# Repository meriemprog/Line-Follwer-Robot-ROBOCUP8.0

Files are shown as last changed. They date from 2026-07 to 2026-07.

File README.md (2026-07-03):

map
Readme · MDPID Line-Follower Robot (ESP32)

An autonomous line-following robot built for competition, running on an ESP32 microcontroller. The robot uses a 6-sensor IR array with a PID control loop to track a line, handles inverted-color (color-swap) track sections, and includes timed maneuver phases tuned for a specific competition course.

Features

6-channel IR sensor array with automatic calibration (white surface / black line) at startup
PID line-tracking control (tunable Kp, Ki, Kd) with anti-windup protection on the integral term
Weighted error calculation — sensor weights can be reconfigured per track segment for sharper or gentler corrections
Timed maneuver sequencing — the main loop uses millis()-based time windows to switch between different speed/PID/weight profiles for different sections of the course (start, straights, curves, etc.)
Inverted-line detection & handling — a dedicated routine (readSensorsinv) detects and follows color-swapped track sections where black/white are reversed
Automatic stop condition — the robot halts when it detects a full stop-line (all 6 sensors active) after completing the course
Push-button start — robot waits for a button press before beginning its run, allowing manual placement on the track
Onboard LED status indicator — used during calibration and inverted-line phases

Hardware

ComponentDescriptionMicrocontrollerESP32Line sensors6x IR/reflectance sensors (analog)Motor driver2x DC motors, H-bridge style (forward/reverse PWM pins per motor)Push buttonUsed to trigger the start of the runOnboard LEDStatus indicator during calibration

Pinout

SignalPinLeft Motor ForwardGPIO 4Left Motor BackwardGPIO 16Right Motor ForwardGPIO 17Right Motor BackwardGPIO 18Status LEDGPIO 2Start ButtonGPIO 34IR Sensors (0–5)GPIO 32, 33, 25, 26, 27, 13

How It Works

Calibration — On boot, the robot is placed on a white surface, then on the black line, so each sensor's min/max reflectance values are recorded (~13s process). Calibration values are printed over Serial for debugging.
Start trigger — The robot waits for a button press before beginning its run.
Line tracking loop — Each cycle:

Reads and binarizes all 6 sensors against the calibrated threshold
Computes a weighted position error from active sensors
Runs the PID controller on the error to produce a correction output
Converts the PID output into differential left/right motor speeds

Course-specific phases — The main loop() uses elapsed time (millis() - t0) to switch between different weight sets, base speeds, and Kp values for different segments of the known competition track.
Inverted-color handling — If the sensor pattern matches a color-inverted section (outer sensors triggered, center sensors not), the robot switches to an inverted read/response routine until it exits that section.
Finish detection — Once the robot detects a full black stop-line (all 6 sensors active) after completing the inverted section, it stops both motors and halts execution.

Configuration

Key tunable parameters near the top of the file:

cppfloat Kp = 43;
float Ki = 0.0005;
float Kd = 8;

int baseSpeed = 150;   // base cruising speed (0–255)
int maxSpeed  = 255;
int minSpeed  = 30;

These — along with the per-segment weights arrays inside loop() — are the main values to retune when adapting the robot to a new track layout.

Usage

Flash competition_code.ino to the ESP32 via the Arduino IDE (select the correct ESP32 board profile).
Open the Serial Monitor at 115200 baud to view calibration output and debug logs.
Power on the robot with it placed on a white area of the track; wait for the LED to turn on/off (white calibration phase).
Move the robot onto the black line when prompted; wait for calibration to complete.
Press the start button to begin the run.
The robot will follow the line autonomously and stop automatically at the finish/stop-line.

Notes

Some code comments and variable names are in French/Darija (e.g. t_lekhra, khrouj, test_tri9_twil), reflecting the original development context — functionally these track timing and state flags for the inverted-line exit sequence.
The timed phases in loop() are tuned for a specific competition track and will need to be re-calibrated (both timings and sensor weights) if reused on a different course. [Uploading CDC-SUIVEUR.pdf…]()

https://github.com/user-attachments/assets/bd51bef6-24f9-4c43-a9d5-c52722ca410f

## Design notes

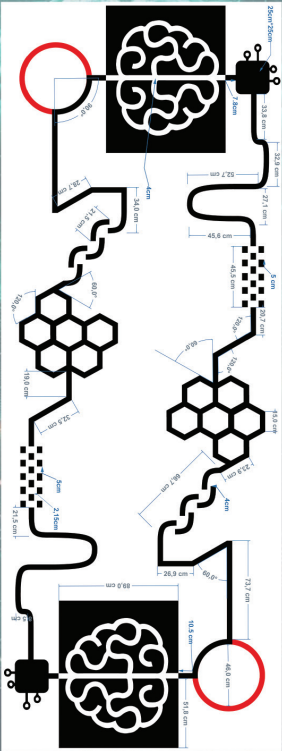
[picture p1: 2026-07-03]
map.png

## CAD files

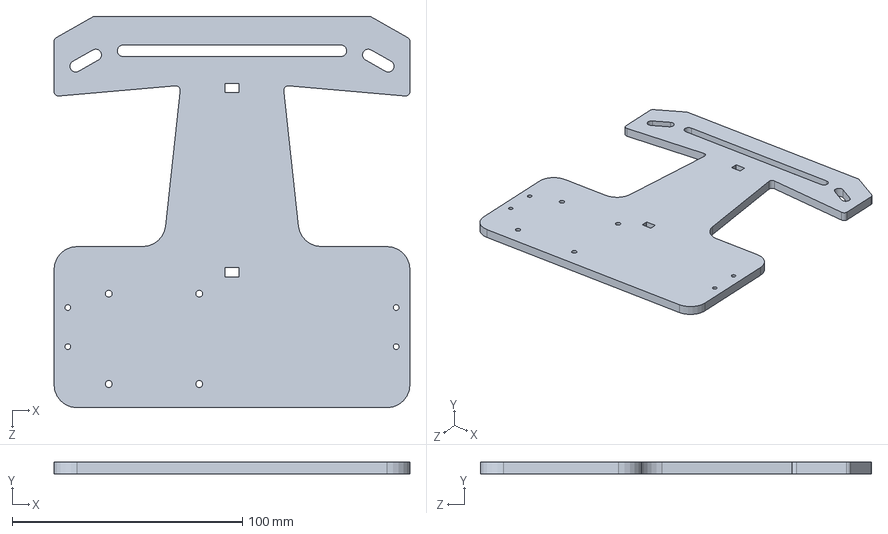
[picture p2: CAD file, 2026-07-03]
Base Conception.sldprt
154.6 x 5.00 x 170.0 mm

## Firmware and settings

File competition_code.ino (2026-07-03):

'"#include<vector>
  //temps de calibrage =13s
  using namespace std;
  const int ML_F = 4;  // PWM pin for Motor A direction 1
  const int ML_B = 16;  // PWM pin for Motor A direction 2  
  const int MR_F = 17;  // PWM pin for Motor B direction 1
  const int MR_B = 18; // PWM pin for Motor B direction 2
  #define LED 2 // internal led 
  const int btnpin=34;
  const int sensorPins[6] = {32,33,25,26,27,13}; 
  float Kp = 43; 
  float Ki = 0.0005; 
  float Kd = 8 ;   
  int error = 0;                  
  int previousError = 0;  
  float integralTerm=0; 
  int derivative = 0; 
  int pidOutput =0;
  bool cerclemode=false;
  bool flechemode=false;
  // Motor Speed Parameters
  int baseSpeed =150;     // Base speed when robot is on line (0-255)
  int maxSpeed = 255;      // Maximum allowed speed
  int minSpeed = 30;       // Minimum speed to overcome friction
  // Sensor Values and Calibration
  int sensorValues[6];     // Raw sensor readings
  int sensorCalibrated[6]; // Calibrated sensor values
  int valblanc[6];        // Minimum values during calibration
  int valnoir[6];        // Maximum values during calibration
  int sensorMin[6]={4095,4095,4095,4095,4095,4095};
  int sensorMax[6]={0,0,0,0,0,0};
  unsigned int t_lekhra ; // instance de khrouj ml couleur inverséée
  bool test_tri9_twil = false;
  unsigned int t0;
  int k=0;
  int k1=0;
  int k2=0;
  int activeCountBefore=0;
  bool test1=false;
  int khrouj =0;



  //Line Position (0 = centered, negative = left, positive = right)
  int linePosition = 0;
  vector<double> weights = {5, 3, 1, -1, -3, -5};
  vector<int>weightscercle={9,7,1,-1,-3,-5};
  void calibrateSensors() {
    int valBlanc[6] = {0, 0, 0, 0, 0, 0};
    int valNoir[6]  = {0, 0, 0, 0, 0, 0};



    Serial.println("=== Calibration Start ===");
    Serial.println("Step 1: Place robot on WHITE area");

    delay(2000); // Time to place it manually
    digitalWrite(LED,HIGH);

    // Measure white surface
    for (int j = 0; j < 50; j++) {
      for (int i = 0; i < 6; i++) {
        valBlanc[i] += abs(analogRead(sensorPins[i]));
      }
      delay(50);
    }
    digitalWrite(LED,LOW);

    delay(2000);
    Serial.println("Step 2: Place robot on BLACK line");
    delay(3000);

    digitalWrite(LED,HIGH);

    // Measure black surface
    for (int j = 0; j < 50; j++) {
      for (int i = 0; i < 6; i++) {
        valNoir[i] +=abs(analogRead(sensorPins[i]));
      }
      delay(50);
    }
    digitalWrite(LED,LOW);

    // Compute average values and save them as min/max calibration
    for (int i = 0; i < 6; i++) {
      sensorMin[i] = abs(valBlanc[i]) / 50;  // White = min reflectivity
      sensorMax[i] = abs(valNoir[i]) / 50;   // Black = max reflectivity
      if (sensorMax[i] < sensorMin[i]) {  // swap if reversed
        int temp = sensorMax[i];
        sensorMax[i] = sensorMin[i];
        sensorMin[i] = temp;
      }
    }


    Serial.println("Calibration complete!");
    for (int i = 0; i < 6; i++) {
      Serial.print("Sensor ");
      Serial.print(i);
      Serial.print(" -> Min: ");
      Serial.print(sensorMin[i]);
      Serial.print("  Max: ");
      Serial.println(sensorMax[i]);
    }
    Serial.println("=========================");
  }
  // MIN of an array 
  int Min(int* T) {
    int min=T[0];
    for(int i=0;i<6;i++){
      if(T[i]<=min){
        min=T[i];
      }
    }
    return min;
  }
  int Max(int* T) {
    int max=T[0];
    for(int i=0;i<6;i++){
      if(T[i]>=max){
        max=T[i];
      }
    }
    return max;
  }
  int stop = 0;

  void readSensors() {
    /*
    * Reads all 6 sensors and converts to binary values
    * Applies calibration to get consistent readings
    */
    for (int i = 0; i < 6; i++) {
      int rawValue = analogRead(sensorPins[i]);
      
      // Apply calibration: map to 0-1000 range
      int calibratedValue = map(rawValue, sensorMin[i], sensorMax[i], 0, 4095);
      
      // Constrain values and convert to binary (0 or 1)
      //calibratedValue = constrain(calibratedValue, 0, 1000);
      sensorCalibrated[i] = (calibratedValue > (Max(sensorMin)+Min(sensorMax))/2) ? 1 : 0; 
    }
  }
  void calculateError() {
    /*
    * Calculates position error based on sensor readings
    * Uses weighted position method for better accuracy
    * Sensor positions: [0, 1, 2, 3, 4, 5] from left to right
    * Weights: [-5, -3, -1, 1, 3, 5] for 6 sensors
    */
    int weightedSum = 0;
    int sensorSum = 0;
    
    // Define weights for each sensor position 
    for (int i = 0; i < 6; i++) {
      weightedSum += sensorCalibrated[i] * weights[i];
      sensorSum += sensorCalibrated[i];
    }
    
    // Calculate error (0 if no sensors detect line)
    if (sensorSum != 0) {
      error = weightedSum;
      linePosition = weightedSum;
    } else {
      // No line detected - use previous error for recovery
      error = previousError > 0 ? 10 : -10; // Continue in last known direction
    }
  }
  void calculatePID() {
    float proportional = Kp * error;
    // Prevent integral windup (limit integral term)
    if (pidOutput>255){
      Ki=0;
    }
    integralTerm += Ki * error;

    derivative = error - previousError;
    float derivativeTerm = Kd * derivative;
    
    previousError = error;
    
    pidOutput = proportional + integralTerm + derivativeTerm;
    
    applyPIDToMotors(pidOutput);
  }
  void applyPIDToMotors(int pidOutput) {
    /*
    * Applies PID output to adjust motor speeds
    * Positive output = turn right, Negative output = turn left
    */
    int leftMotorSpeed = (baseSpeed - abs(pidOutput)) - pidOutput;
    int rightMotorSpeed = (baseSpeed - abs(pidOutput)) + pidOutput;
    // Constrain speeds to valid PWM range
    leftMotorSpeed = constrain(leftMotorSpeed, minSpeed, maxSpeed);
    rightMotorSpeed = constrain(rightMotorSpeed, minSpeed, maxSpeed);
    if (abs(error)>=5){
      if(rightMotorSpeed<leftMotorSpeed)
        rightMotorSpeed=0;
      else
        leftMotorSpeed=0;
    }
    // Set motor speeds
    setMotorSpeed(leftMotorSpeed, rightMotorSpeed);
  }
  void setMotorSpeed(int leftSpeed, int rightSpeed) {
    /*
    * Controls 4 PWM motors based on calculated speeds
    * Assumes motor configuration:
    * - Motor A: Left side (pins A1, A2)
    * - Motor B: Right side (pins B1, B2)
    */
    
    // Left Motor Control
    if (leftSpeed > 0) {
      // Forward motion
      analogWrite(ML_F, leftSpeed);
      analogWrite(ML_B, 0);
    } else {
      // Backward motion (if needed for sharp turns)
      analogWrite(ML_F, 0);
      analogWrite(ML_B, abs(leftSpeed));
    }
    
    // Right Motor Control
    if (rightSpeed > 0) {
      // Forward motion
      analogWrite(MR_F, rightSpeed);
      analogWrite(MR_B, 0);
    } else {
      // Backward motion (if needed for sharp turns)
      analogWrite(MR_F, 0);
      analogWrite(MR_B, abs(rightSpeed));
    }
  }
  int activeCount() {
    readSensors();
    int count = 0;
    for (int i = 0; i < 6; i++) {
      if (sensorCalibrated[i] == 1) {
        count++;
      }
    }
    return count;
  }
  void setup() {
    // Initialize motor pins as OUTPUT
    pinMode(ML_F, OUTPUT);
    pinMode(ML_B, OUTPUT);
    pinMode(MR_F, OUTPUT);
    pinMode(MR_B, OUTPUT);
    pinMode(LED,OUTPUT);
    pinMode(btnpin, INPUT);
    // Initialize serial communication for debugging
    Serial.begin(115200);
    while (!Serial) {delay(10);}   
    for (int i = 0; i < 6; i++) {
      pinMode(sensorPins[i], INPUT);
    }
    // Calibrate sensors at startup
    calibrateSensors(); 
    Serial.println("Line Follower Robot Ready!");
    delay(1000);
    while(digitalRead(btnpin)==1){delay(10);}
    t0=millis();
  }
  void stopMotors() {
    analogWrite(ML_F, 0);
    analogWrite(ML_B, 0);
    analogWrite(MR_F, 0);
    analogWrite(MR_B, 0);
  }
  void readSensorsinv(){
    /*
    * Reads all 6 sensors and converts to binary values
    * Applies calibration to get consistent readings
    */
    for (int i = 0; i < 6; i++) {
      int rawValue = analogRead(sensorPins[i]);
      
      // Apply calibration: map to 0-1000 range
      int calibratedValue = map(rawValue, sensorMin[i], sensorMax[i], 0, 4095);
      
      // Constrain values and convert to binary (0 or 1)
      //calibratedValue = constrain(calibratedValue, 0, 1000);
      sensorCalibrated[i] = (calibratedValue > (Max(sensorMin)+Min(sensorMax))/2) ? 0 : 1; 
    }
  }
  void loop() {
    // Main control loop
    readSensors();           // Read all 6 sensor values
    unsigned int t1=millis();
    while(millis() - t0 >=200 && millis() - t0 <= 910){
      readSensors();
      baseSpeed=240;
      Kp=47;
      weights = {0, 0, 2, -2, 0, 0};
      k++;
      calculateError();
      calculatePID();
      delay(5);
    }
    baseSpeed=130;
    Kp=43;
    while(k!=0&& millis()-t0>=1500&&millis()-t0<=4800){
      readSensors();
      weights = {1, 1, 1, -1, -2,-3};
      calculateError();
      calculatePID();
      delay(5);
    }
    while(millis()-t0>4800&&millis()-t0<=8500){
      readSensors();
      weights = {10, 3, 1, -1, -3, -10};
      baseSpeed=200;
      Kp=45;
      calculateError();
      calculatePID();
      delay(5);
      k1++;
    }
    
    // partie des couleur inversée
    while(sensorCalibrated[0]==1&&sensorCalibrated[1]==1&&sensorCalibrated[4]==1&&sensorCalibrated[5]==1&&(sensorCalibrated[2]==0||sensorCalibrated[3]==0)){
      readSensorsinv();
      while(!(sensorCalibrated[0]==1&&sensorCalibrated[1]==1&&sensorCalibrated[4]==1&&sensorCalibrated[5]==1&&(sensorCalibrated[2]==0||sensorCalibrated[3]==0))){
        readSensorsinv();
        weights = {5, 7, 1, -1, -3, -5};
        calculateError();
        calculatePID();
        delay(5);
      }
      if (stop==0){
        stop = 1;
      }
      readSensors();
    }
    if (stop>=1 && khrouj==0){
      
      weights = {5, 3, 1, -1, -3, -5};
      khrouj++;
      t_lekhra = millis();
    }
    while(millis()-t_lekhra <= 800 && khrouj!=0){
      readSensors();
      baseSpeed = 230;
      calculateError();
      calculatePID();
      delay(5);
      if (test_tri9_twil == false){
        test_tri9_twil = true;
      }
    }
    while(test_tri9_twil==true){
      readSensors();
      baseSpeed = 135;
      calculateError();
      calculatePID();
      delay(5);
      if (stop==1 && activeCount()==6){
        delay(300);
        stopMotors();
        while(true){};
      }
      
      }
    digitalWrite(LED,LOW);
    weights = {5, 3, 1, -1, -3, -5};
    Serial.println(); // nouvelle ligne*/
    calculateError();
    calculatePID();
    delay(5); // Small delay for stability
  }
